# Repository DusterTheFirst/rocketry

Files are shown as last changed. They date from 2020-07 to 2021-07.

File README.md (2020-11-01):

# Thrust Vector Controlled Model Rockets

This repository consists of the rockets that Zachary Kohnen has created. These rockets use active TVC based stabilization.
The models for each rocket can be found in the rockets directory, and the flight firmware for each project can be found in the firmware directory.
Below is a list of the rockets, basic information about them, and hyperlinks to their respective information.

You can access a development log published online at [rocketry.dusterthefirst.com](//rocketry.dusterthefirst.com) file.

# License
    Thrust Vector Controlled Model Rockets
    Copyright (C) 2020  Zachary Kohnen (DusterTheFirst)

    This program is free software: you can redistribute it and/or modify
    it under the terms of the GNU General Public License as published by
    the Free Software Foundation, either version 3 of the License, or
    (at your option) any later version.

    This program is distributed in the hope that it will be useful,
    but WITHOUT ANY WARRANTY; without even the implied warranty of
    MERCHANTABILITY or FITNESS FOR A PARTICULAR PURPOSE.  See the
    GNU General Public License for more details.

    You should have received a copy of the GNU General Public License
    along with this program.  If not, see <https://www.gnu.org/licenses/>.

<sub>All content in this repository was developed and maintained by [@DusterTheFirst (Zachary Kohnen)](https://github.com/dusterthefirst). Software and firmware is licensed under the [`GNU GPL 3.0 license`](./LICENSE.md) and CAD models and other artistic works are licensed under the [`CreativeCommons Attribution-NonCommercial-ShareAlike license`](http://creativecommons.org/licenses/by-nc-sa/4.0/)</sub>

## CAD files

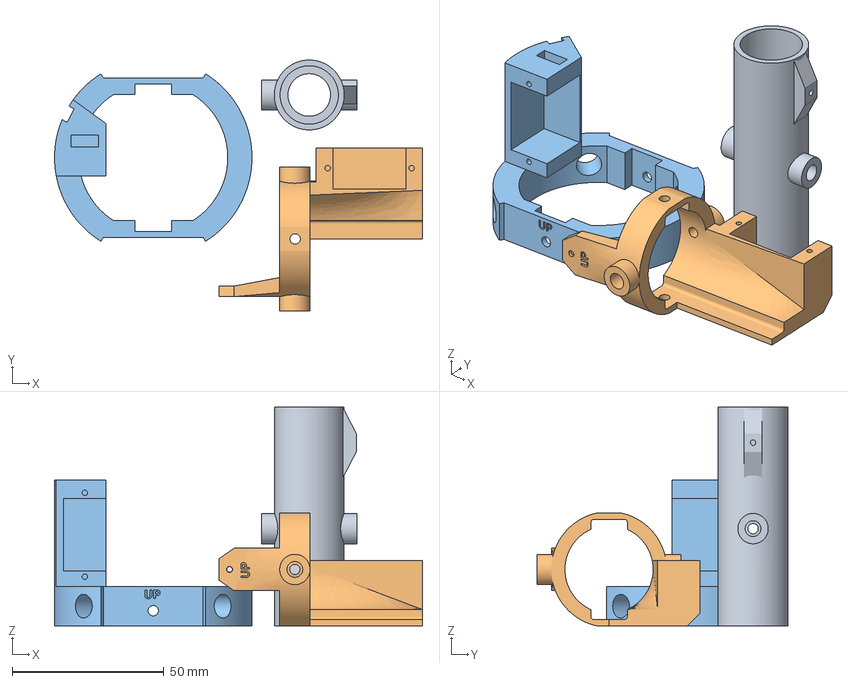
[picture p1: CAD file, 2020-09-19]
rockets/slider/freecad/slice/Full TVC Mount.3mf
121.1 x 82.6 x 72.0 mm
Center Gimbal.stl
Middle Gimbal.stl
Outer Gimbal.stl

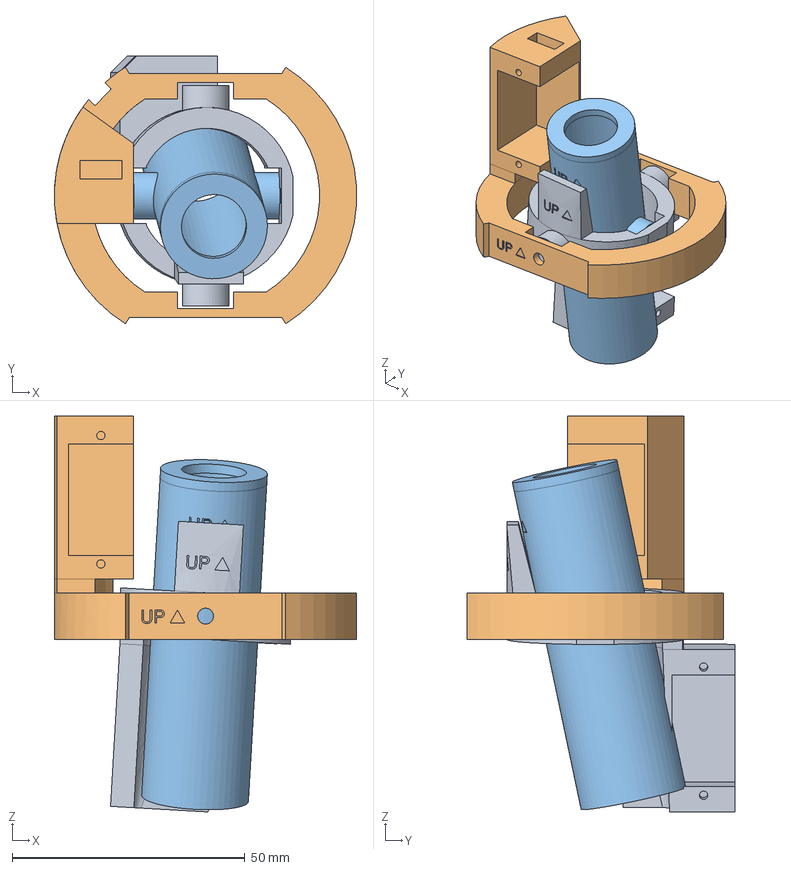
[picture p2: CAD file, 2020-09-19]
rockets/slider/freecad/slider_tvc_assembly.FCStd
64.9 x 57.5 x 85.1 mm
slider_Middle Gimbal_001
slider_Outer Gimbal_001
slider_Center Gimbal_001

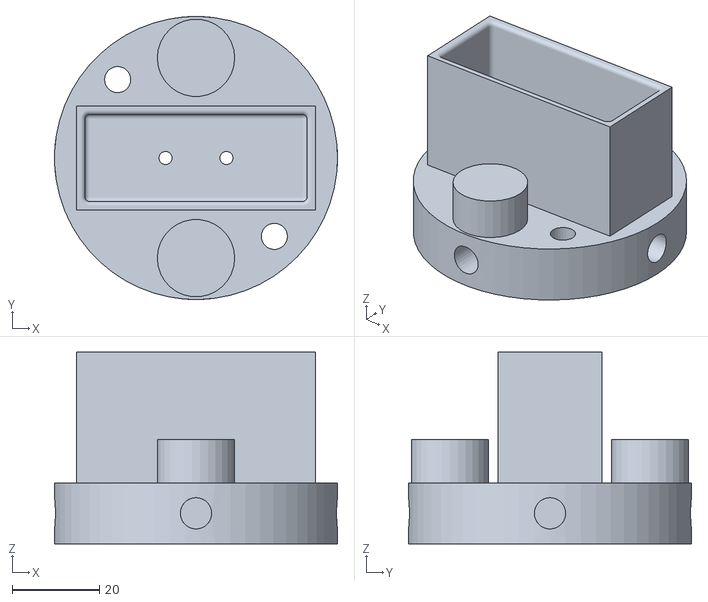
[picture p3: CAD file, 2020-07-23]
rockets/models/slider/renders/Parachute Holder.stl
65.0 x 65.0 x 44.0

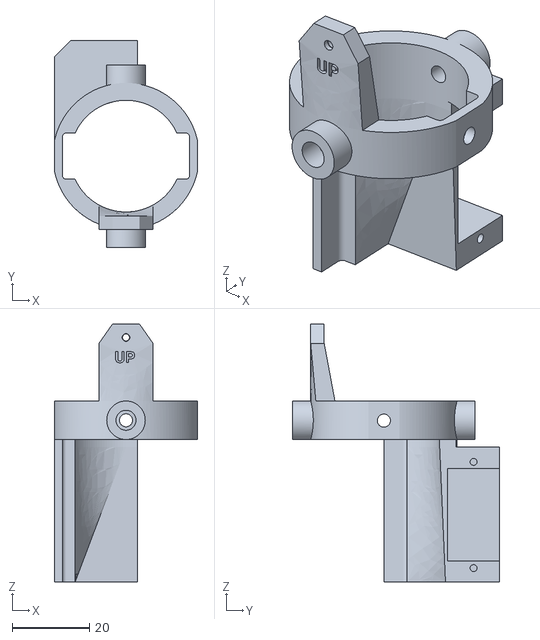
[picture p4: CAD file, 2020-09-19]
rockets/slider/freecad/renders/Middle Gimbal.stl
37.1 x 53.7 x 67.0

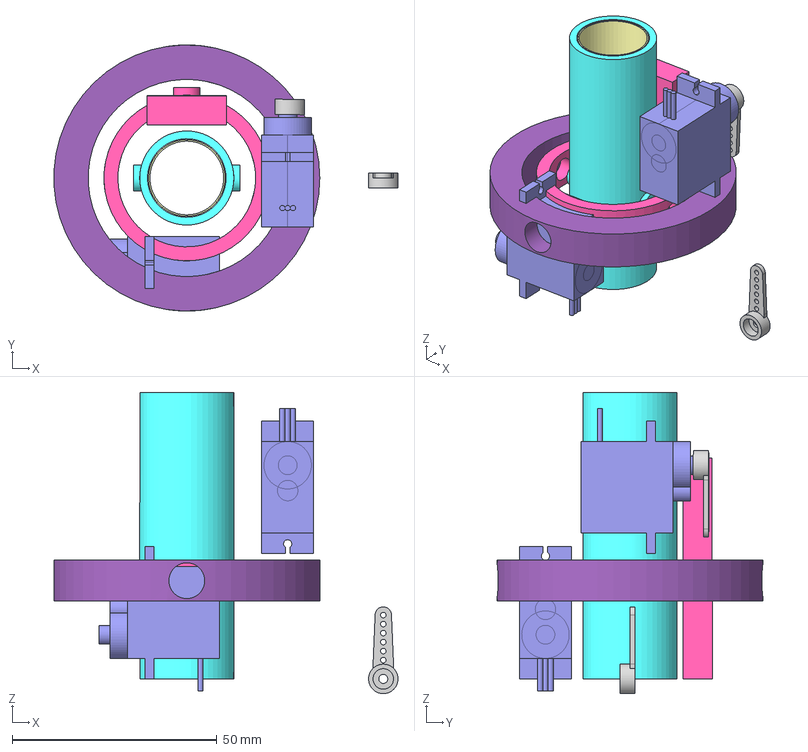
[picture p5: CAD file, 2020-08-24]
rockets/slider/slider.FCStd
84.0 x 65.0 x 73.6 mm
18mm x 2.75" Motor Tube
Center Motor Gimbal
Middle Motor Gimbal
Outer Motor Gimbal
Micro Servo (Tower Pro SG92R) 001 x 2
Micro Servo (Tower Pro SG92R) 002 x 2
Tower Pro Servo Horn 002 x 2
Tower Pro Servo Horn 001 x 2

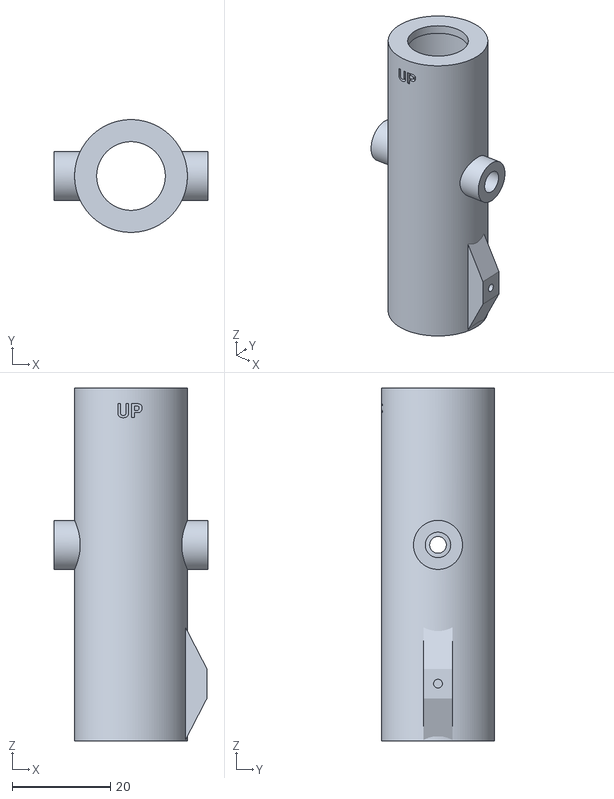
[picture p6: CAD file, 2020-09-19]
rockets/slider/freecad/renders/Center Gimbal.stl
31.4 x 23.0 x 72.0

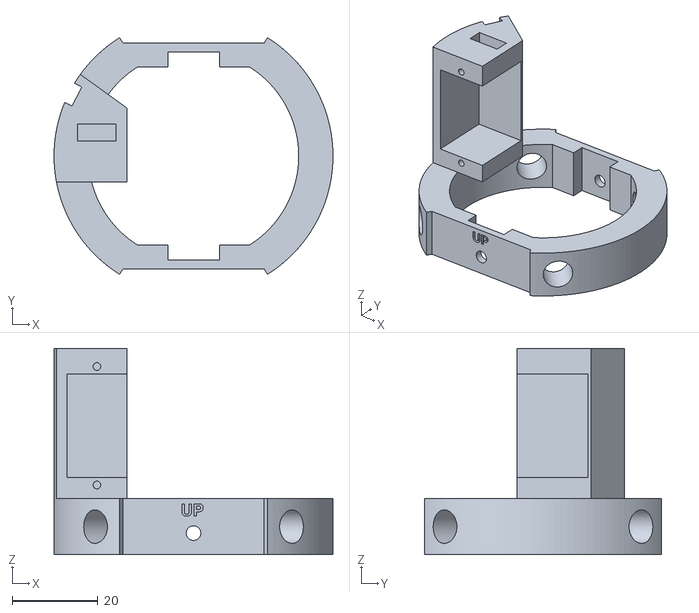
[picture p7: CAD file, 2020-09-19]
rockets/slider/freecad/renders/Outer Gimbal.stl
65.0 x 55.1 x 48.0

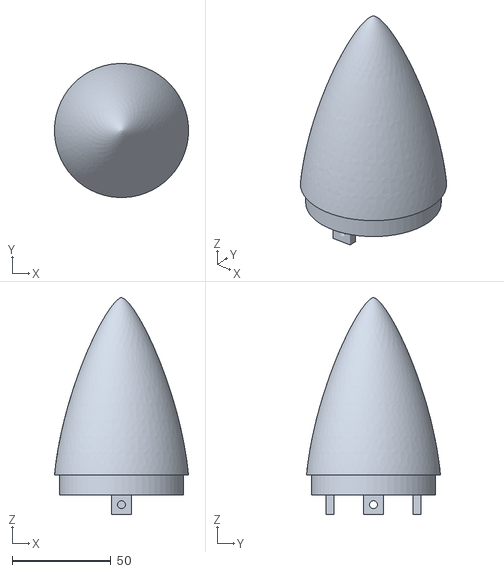
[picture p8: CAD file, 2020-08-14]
rockets/slider/freecad/renders/Nose Cone.stl
68.0 x 67.9 x 110.0

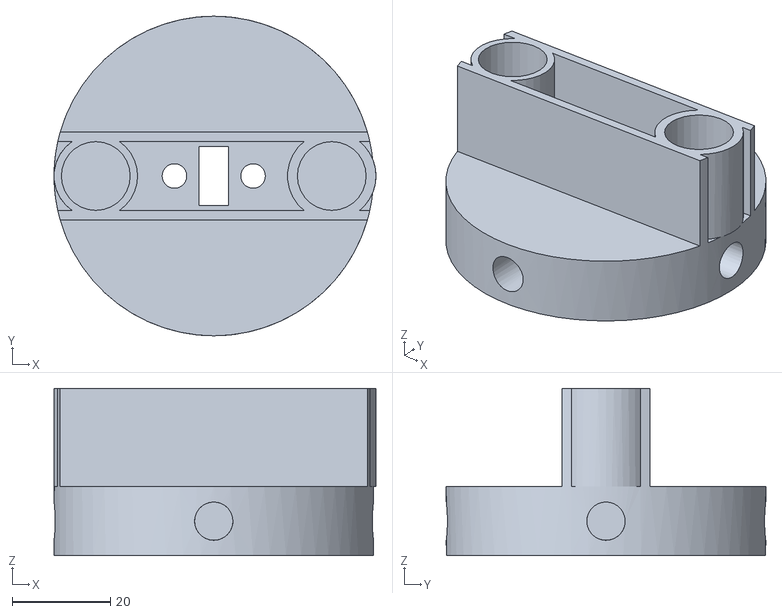
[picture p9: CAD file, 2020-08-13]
rockets/slider/freecad/renders/Parachute Holding.stl
65.5 x 65.0 x 34.0

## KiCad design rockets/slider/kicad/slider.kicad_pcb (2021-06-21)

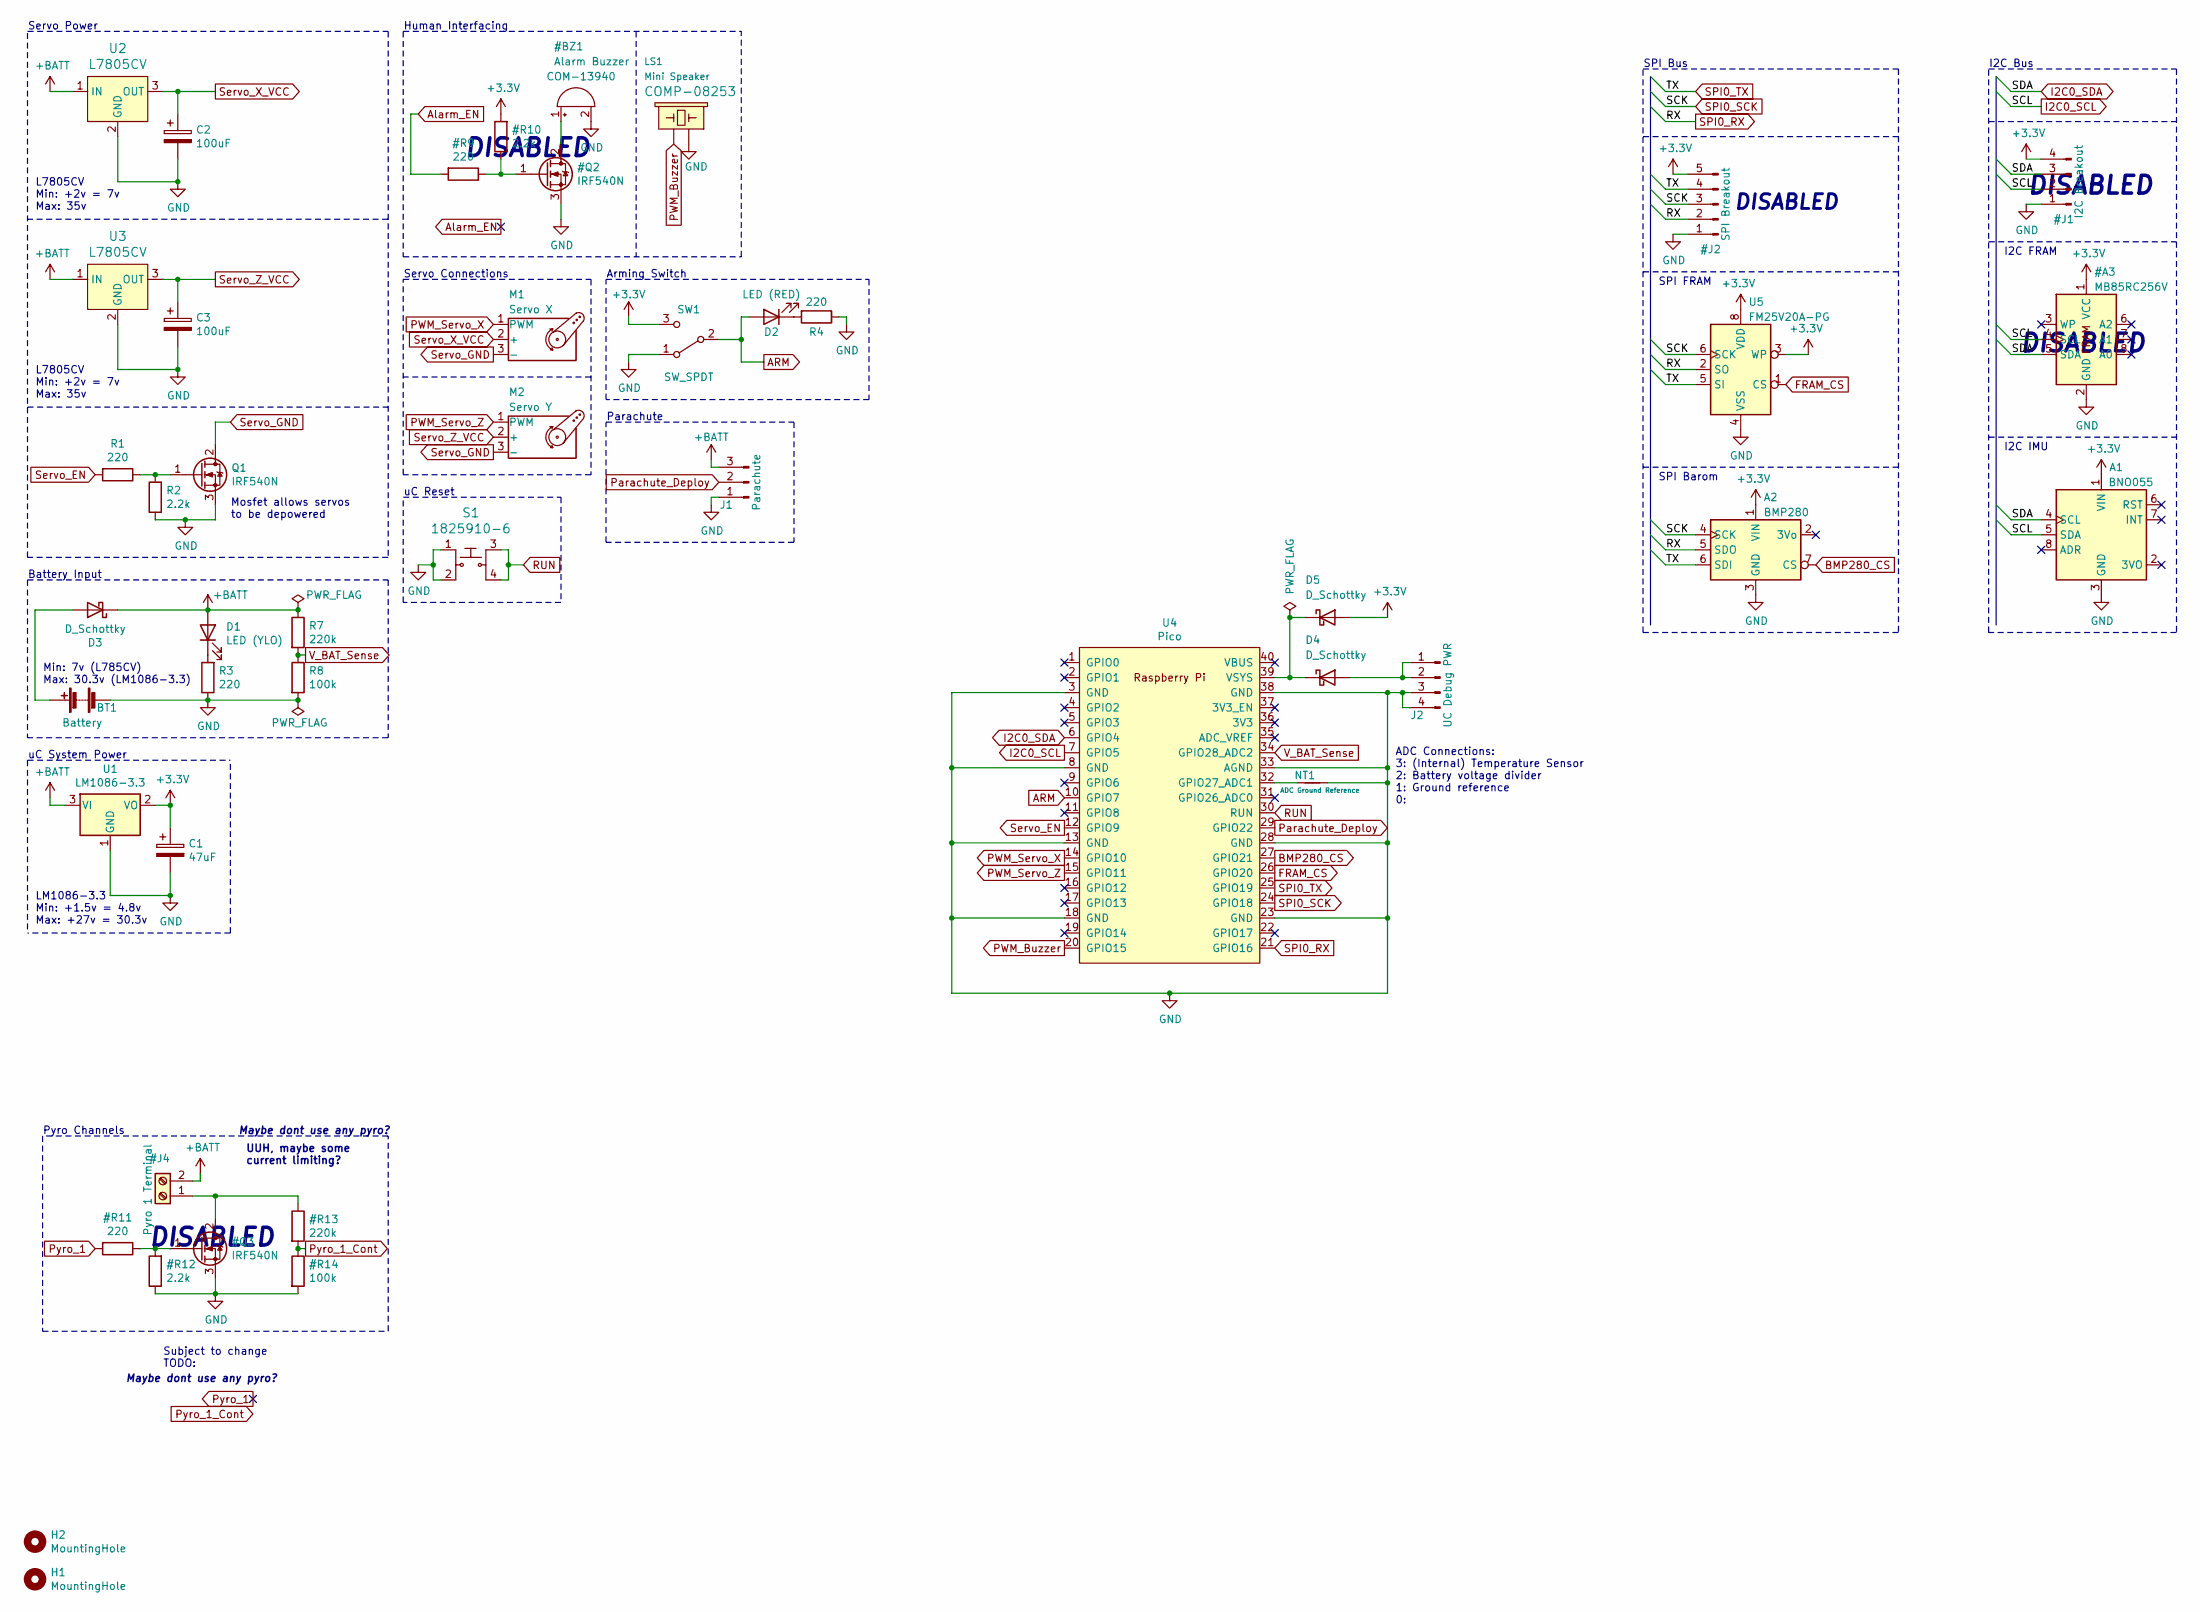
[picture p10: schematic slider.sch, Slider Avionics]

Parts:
A1: BNO055; Adafruit_BNO055
A2: BMP280; Adafruit_BMP280
BT1: Battery; TerminalBlock_Phoenix_PT-1,5-2-3.5-H_1x02_P3.50mm_Horizontal
C1: 47uF; CP_Radial_D5.0mm_P2.50mm
C2, C3: 100uF; CP_Radial_D6.3mm_P2.50mm
D1: LED (YLO); LED_D5.0mm
D2: LED (RED); LED_D5.0mm
D3, D4, D5: D_Schottky; D_DO-35_SOD27_P7.62mm_Horizontal
H1, H2: MountingHole; MountingHole_3mm
J1: Parachute; PinHeader_1x03_P2.54mm_Vertical
J2: UC Debug PWR; PinHeader_1x04_P2.54mm_Vertical
LS1: Mini Speaker; BUZZER-12MM
M1: Servo X; PinHeader_1x03_P2.54mm_Vertical
M2: Servo Y; PinHeader_1x03_P2.54mm_Vertical
NT1: ADC Ground Reference; NetTie-2_SMD_Pad0.5mm
Q1: IRF540N; TO-220-3_Vertical
R1, R3, R4: 220; R_Axial_DIN0207_L6.3mm_D2.5mm_P7.62mm_Horizontal
R2: 2.2k; R_Axial_DIN0207_L6.3mm_D2.5mm_P7.62mm_Horizontal
R7: 220k; R_Axial_DIN0207_L6.3mm_D2.5mm_P7.62mm_Horizontal
R8: 100k; R_Axial_DIN0207_L6.3mm_D2.5mm_P7.62mm_Horizontal
S1: 1825910-6; Switch_Tactile_THT_6x6mm; MPN 1825910-6; Digi-Key_PN 450-1650-ND
SW1: SW_SPDT; Switch_Toggle_ATE1D-2M3-10-Z
U1: LM1086-3.3; TO-220-3_Vertical
U2, U3: L7805CV; TO-220-3_Vertical; MPN L7805CV; Digi-Key_PN 497-1443-5-ND
U4: Pico; RPi_Pico_TH_Perfboard
U5: FM25V20A-PG; FM25V20A

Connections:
ARM: D2.2 (A), SW1.2 (B), U4.10 (GPIO7)
BMP280_CS: A2.7 (CS), U4.27 (GPIO21)
FRAM_CS: U4.26 (GPIO20), U5.1 (CS)
unnamed: BT1.1 (+), D3.2 (A)
unnamed: D1.1 (K), R3.2
unnamed: D2.1 (K), R4.2
unnamed: D4.1 (K), D5.1 (K), U4.39 (VSYS)
unnamed: D4.2 (A), J2.1, J2.2
unnamed: NT1.2, U4.32 (GPIO27_ADC1)
unnamed: Q1.1 (G), R1.1, R2.2
PWM_Buzzer: LS1.+ (1), U4.20 (GPIO15)
PWM_Servo_X: M1.1 (PWM), U4.14 (GPIO10)
PWM_Servo_Z: M2.1 (PWM), U4.15 (GPIO11)
Parachute_Deploy: J1.2, U4.29 (GPIO22)
RUN: S1.3, S1.4, U4.30 (RUN)
Servo_EN: R1.2, U4.12 (GPIO9)
Servo_GND: M1.3 (-), M2.3 (-), Q1.2 (D)
Servo_X_VCC: C2.1, M1.2 (+), U2.3 (OUT)
Servo_Z_VCC: C3.1, M2.2 (+), U3.3 (OUT)
V_BAT_Sense: R7.2, R8.1, U4.34 (GPIO28_ADC2)

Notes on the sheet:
Servo Power
uC System Power
Battery Input
Servo Connections
Human Interfacing
L7805CV Min: +2v = 7v Max: 35v
LM1086-3.3 Min: +1.5v = 4.8v Max: +27v = 30.3v
Min: 7v (L785CV) Max: 30.3v (LM1086-3.3)
uC Reset
Mosfet allows servos to be depowered
UUH, maybe some current limiting?
Pyro Channels
Subject to change TODO:
Arming Switch
Maybe dont use any pyro?
I2C Bus
SPI Bus
I2C FRAM
I2C IMU
SPI FRAM
SPI Barom
DISABLED
Parachute
ADC Connections: 3: (Internal) Temperature Sensor 2: Battery voltage divider 1: Ground reference 0:

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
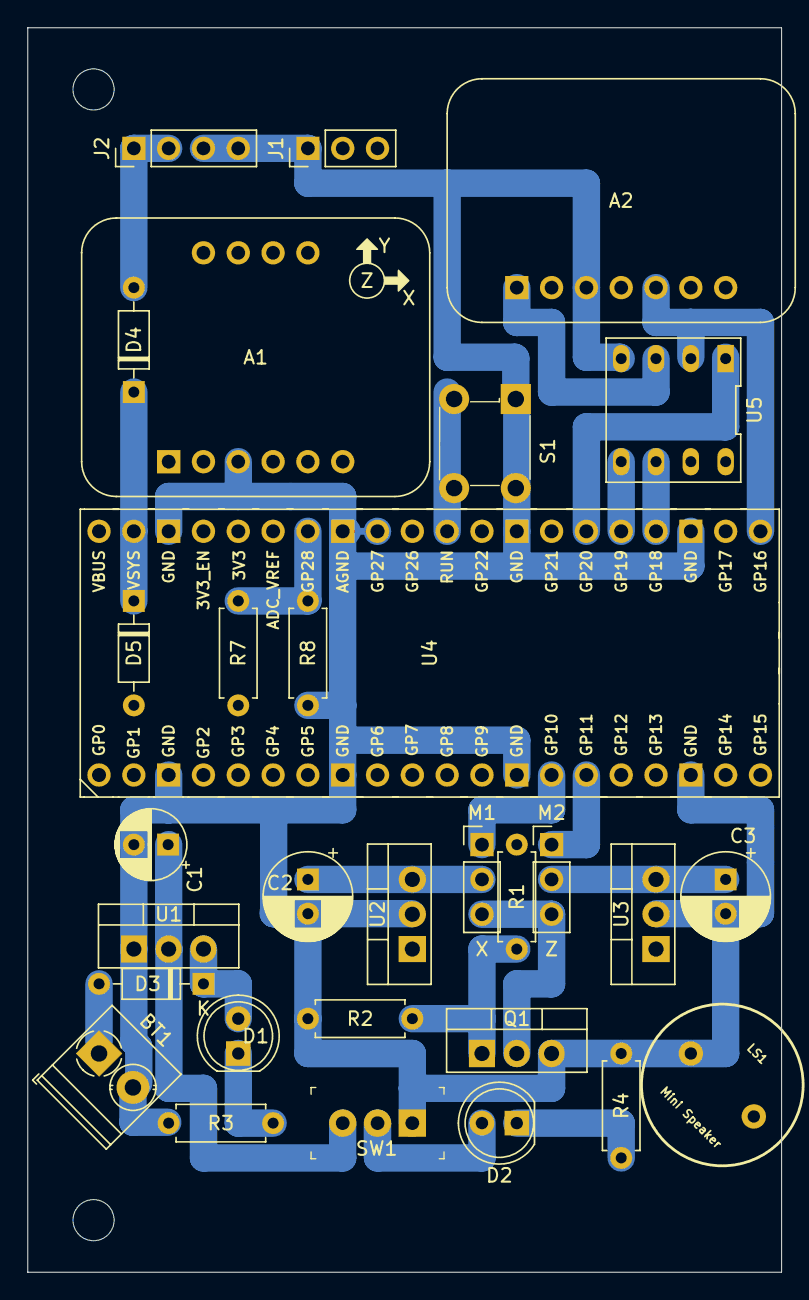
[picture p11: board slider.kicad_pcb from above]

Board: 2 copper layers, 55.0 x 90.8 mm, 33 parts (1 on the bottom side), 28 nets.

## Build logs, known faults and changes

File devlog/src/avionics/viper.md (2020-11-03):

# Viper

> **Status**: In development
> 
> **Created**: August 3, 2020
>
> **First Flown**: Never
>
> **Rockets**: [Slider]

Viper, much like Slider has a lot of rough edges. I, being a software
developer at heart love code that works well and looks good, so I
eventually end up spending way too much time going into detail and
trying to make it perfect while neglecting the hardware. This can be
seen in the [first entry into the devlog][1].

The avionics will control a rocket using TVC given inputs from an IMU.
It will estimate the position of the rocket relative to its position on
the launchpad, attempting to stay pointing towards the sky.

[Slider]: ../rockets/slider.md
[1]: ./viper/2020-11-03-perfection.md

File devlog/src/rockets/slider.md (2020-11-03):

# Slider

> **Status**: In development
> 
> **Created**: July 17, 2020
>
> **First Flown**: Never
>
> **Avionics**: [Viper]

Slider is the first rocket to be made, It is very rough around the edges
but that is expected for a first. The rocket uses TVC based stabilization
during powered flight. The TVC gimbal uses 2 servos to provide around 5
degrees of movement in both directions. The gimbal is able to house any
18mm motor (generally an Estes A-C model rocket motor). The rocket is
only designed for powered flight, it relies on a parachute (or 2) to
slow its decent back to the ground. This parachute system is designed
to use no black powder and to be as reusable and safe as possible.
From testing, [it seems to be very finicky][chute-test] and needs more development
before a good solution is found.

All custom made parts for the rocket are 3d printed out of PLA plastic.
The plastic has been tested and [seems to be able to handle the stress
and heat from the rocket motor][tvc-test].

[Viper]: ../avionics/viper.md
[tvc-test]: ./slider/2020-10-25-tvc.html
[chute-test]: ./slider/2020-08-13-parachute.html

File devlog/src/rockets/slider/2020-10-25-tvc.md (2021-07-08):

# TVC Static Fire I
<sup>October 25, 2020</sup>

## Purpose
This test is designed to test the static force capabilities of the 2 axis TVC gimbal.
Although simple, this test aims to demonstrate that the TVC mount can hold its own under
load as well as maintain its strength under the high temperatures that the motor produces.

## Method
The TVC mount is clamped down to a stand, with the exhaust of the motor facing upwards with
no obstructions directly below or above to allow the exhaust and ejection charge to vent
safely. To protect the grass from the ejection charge, the exhaust guard from a launch pad
is placed below the mount.

<details>
    <summary>The static fire mount setup</summary>
    <a href="https://cdn.dusterthefirst.com/rocketry/rockets/slider/2020/10/25/setup1.jpg">
        
    </a>
</details>

<details>
    <summary>Another angle of the static fire mount setup</summary>
    <a href="https://cdn.dusterthefirst.com/rocketry/rockets/slider/2020/10/25/setup2.jpg">
        
    </a>
</details>

The TVC mount is then filled with a rocket motor tube and a rocket motor with some tape around
the outside in order to increase the friction and ensure the motor does not leave the motor tube.
The motor should be setup with a starter and plug and inserted into the TVC mount's tube.

Once the motor is inserted into the mount, the starter's wires should be attached and area should be cleared.
After the area is prepared and safe, the motor should be fired.

After the motor has finished firing and the ejection charge has been vented, the motor should be removed from
the stand and the TVC mount should be thoroughly inspected for any problems before repeating the process with
another motor.

The process is repeated with both a B4 and C6 estes black powder motor

### 3d Models Used
- [Center Gimbal](https://github.com/DusterTheFirst/rocketry/blob/b0cf1f1de8338ad24c0d549cec9aca23268d9cd0/rockets/slider/renders/Center%20Gimbal.stl)
- [Middle Gimbal](https://github.com/DusterTheFirst/rocketry/blob/b0cf1f1de8338ad24c0d549cec9aca23268d9cd0/rockets/slider/renders/Middle%20Gimbal.stl)
- [Outer Gimbal](https://github.com/DusterTheFirst/rocketry/blob/b0cf1f1de8338ad24c0d549cec9aca23268d9cd0/rockets/slider/renders/Outer%20Gimbal.stl)

The three above models come together to form the TVC gimbal with them nested in descending order,
with the `Center Gimbal` being the inner most layer.

### Footage

#### B motor
<details>
    <summary>Full speed video of a B motor in the test stand <a href="https://cdn.dusterthefirst.com/rocketry/rockets/slider/2020/10/25/static-b-fullspeed.mp4">(link)</a></summary>
    <video height="240" controls>
        <source src="https://cdn.dusterthefirst.com/rocketry/rockets/slider/2020/10/25/static-b-fullspeed.mp4" type="video/mp4">
    </video>
</details>

<details>
    <summary>Slow motion video of a B motor in the test stand <a href="https://cdn.dusterthefirst.com/rocketry/rockets/slider/2020/10/25/static-b-slowmo.mp4">(link)</a></summary>
    <video height="240" controls>
        <source src="https://cdn.dusterthefirst.com/rocketry/rockets/slider/2020/10/25/static-b-slowmo.mp4" type="video/mp4">
    </video>
</details>

#### C motor
<details>
    <summary>Full speed video of a C motor in the test stand <a href="https://cdn.dusterthefirst.com/rocketry/rockets/slider/2020/10/25/static-c-fullspeed.mp4">(link)</a></summary>
    <video height="240" controls>
        <source src="https://cdn.dusterthefirst.com/rocketry/rockets/slider/2020/10/25/static-c-fullspeed.mp4" type="video/mp4">
    </video>
</details>

<details>
    <summary>Slow motion video of a C motor in the test stand <a href="https://cdn.dusterthefirst.com/rocketry/rockets/slider/2020/10/25/static-c-slowmo.mp4">(link)</a></summary>
    <video height="240" controls>
        <source src="https://cdn.dusterthefirst.com/rocketry/rockets/slider/2020/10/25/static-c-slowmo.mp4" type="video/mp4">
    </video>
</details>

## Findings
The PLA plastic was unaffected by the heat of the motor, most probably due to the short amount of time the heat
was applied to the mount and the Kraft Paper motor tube acting as insulation.

The TVC mount held up to the forces of both motors very well, most probably due to the joints being made of
metal screws and metal inserts. There is not data however on how the servos will be able to handle pivoting the
mount under load.

The exhaust from the motor did not affect the bottom (when the rocket is facing upright) of the motor mount however,
the dirty ejection charge left the top of the motor mount covered in soot, but does not seem to have melted any plastic
or caused any deformation to the plastic construction.

## Changes To Implement
None

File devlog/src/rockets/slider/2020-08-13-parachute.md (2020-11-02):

# Parachute Deploy Test I
<sup>August 13, 2020</sup>

## Purpose
To test the nose cone deployment mechanism's practicality and durability before continuing
development of this design

## Method
The nose cone was assembled with nylon fishing line with nichrome wire wrapped around each tie down line which was then fed
through the holes in the parachute holder and around a push-rod perpendicular to the hole to hold them in place.
The nichrome wire was then supplied current, heating it up and eventually melting the nylon wires.

### 3d Models Used
- [Nose Cone](https://github.com/DusterTheFirst/rocketry/blob/a1a50608c714fe1a907a077f69319fac23ef29f5/rockets/slider/renders/Nose%20Cone.stl)
- [Parachute Holder](https://github.com/DusterTheFirst/rocketry/blob/a1a50608c714fe1a907a077f69319fac23ef29f5/rockets/slider/renders/Parachute%20Holder.stl)

## Findings
The nichrome wire is very reliable in heating up, but not enough that we can guarantee
two nichrome wires to cut through their hold down strings at the same time. In the test,
only one of the wires was cut before the nosecone flew off. When the nose cone was released,
it remained attached to the hold down assembly due to one of the hold down lines remaining uncut.
This lead us to understand that in order to use nichrome wire as a release mechanism,
we must design the release in such a way that it will only use one hold down point.

## Changes To Implement
- Redesign Nose Cone [(done)](https://github.com/DusterTheFirst/rocketry/blob/00949badd6df8fbdd533ba6b04284b056b241a8f/rockets/slider/renders/Nose%20Cone.stl)
    - One, central, tie down point
    - Attachment point(s) for parachute(s)
- Redesign parachute holding mechanism [(done)](https://github.com/DusterTheFirst/rocketry/blob/00949badd6df8fbdd533ba6b04284b056b241a8f/rockets/slider/renders/Parachute%20Holding.stl)
    - One central tie down point
    - Container(s) for parachute(s)
    - Gap around where nichrome wire will be placed as to not melt any PLA plastic

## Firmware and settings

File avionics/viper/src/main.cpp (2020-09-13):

#include "interop/cpp.h"
#include "oxide.h"
#include <Adafruit_BMP280.h>
#include <Adafruit_BNO055.h>
#include <Adafruit_Sensor.h>
#include <Arduino.h>
#include <InternalTemperature.h>
#include <Plotter.h>
#include <Wire.h>

Adafruit_BNO055 bno(55, 0x29);
Adafruit_BMP280 bmp;

Plotter p;

Avionics avionics = create_avionics();
SensorData *data = &avionics.sensor_data;

void setup() {
    p.Begin(); // start plotter

    // BNO-055
    p.AddTimeGraph("Absolute Orientation (deg)", 300,
                   "X", data->bno055.orientation.euler.x,
                   "Y", data->bno055.orientation.euler.y,
                   "Z", data->bno055.orientation.euler.z);
    // p.AddTimeGraph("Absolute Orientation (quaterion)", 300,
    //                "W", data->bno055.orientation.quaterion.w(),
    //                "X", data->bno055.orientation.quaterion.x(),
    //                "Y", data->bno055.orientation.quaterion.y(),
    //                "Z", data->bno055.orientation.quaterion.z());
    p.AddTimeGraph("Angular Velocity (rad/s)", 300,
                   "X", data->bno055.angular_velocity.x,
                   "Y", data->bno055.angular_velocity.y,
                   "Z", data->bno055.angular_velocity.z);
    p.AddTimeGraph("Acceleration (m/s^2)", 300,
                   "X", data->bno055.acceleration.both.x,
                   "Y", data->bno055.acceleration.both.y,
                   "Z", data->bno055.acceleration.both.z);
    p.AddTimeGraph("Linear Acceleration (m/s^2)", 300,
                   "X", data->bno055.acceleration.linear.x,
                   "Y", data->bno055.acceleration.linear.y,
                   "Z", data->bno055.acceleration.linear.z);
    p.AddTimeGraph("Gravity (m/s^2)", 300,
                   "X", data->bno055.acceleration.gravity.x,
                   "Y", data->bno055.acceleration.gravity.y,
                   "Z", data->bno055.acceleration.gravity.z);
    p.AddTimeGraph("Magnetic Field (uT)", 300,
                   "X", data->bno055.magnetic_field.x,
                   "Y", data->bno055.magnetic_field.y,
                   "Z", data->bno055.magnetic_field.z);
    p.AddTimeGraph("Preassure and Altitude", 300,
                   "Pressure (Pa)", data->bmp280.pressure,
                   "Approx. Altitude (m)", data->bmp280.altitude);
    p.AddTimeGraph("Temperature (*C)", 300,
                   "BNO-055", data->bno055.temperature,
                   "BMP-280", data->bmp280.temperature,
                   "Teensy", data->teensy.temperature);

    /* Initialise the sensors */
    if (!bno.begin()) {
        Serial.print("Could not connect to BNO055");

        error_chime(Peripheral::BNO055);
    }

    bno.setExtCrystalUse(true);

    if (!bmp.begin()) {
        Serial.println("Could not connect to BMP280");

        error_chime(Peripheral::BMP280);
    }

    init_avionics(&avionics);
    startup_chime();
}

void loop_1Hz() {
    data->bno055.temperature = bno.getTemp();
    data->bmp280.temperature = bmp.readTemperature();
    data->teensy.temperature = InternalTemperature.readTemperatureC();
}

void loop_10Hz() {
}

void loop_20Hz() {
    data->bno055.magnetic_field = to_rust_vec(bno.getVector(Adafruit_BNO055::VECTOR_MAGNETOMETER));
}

void loop_100Hz() {
    data->bno055.acceleration.both = to_rust_vec(bno.getVector(Adafruit_BNO055::VECTOR_ACCELEROMETER));
    data->bno055.acceleration.linear = to_rust_vec(bno.getVector(Adafruit_BNO055::VECTOR_LINEARACCEL));
    data->bno055.acceleration.gravity = to_rust_vec(bno.getVector(Adafruit_BNO055::VECTOR_GRAVITY));
    data->bno055.angular_velocity = to_rust_vec(bno.getVector(Adafruit_BNO055::VECTOR_GYROSCOPE));
    data->bno055.orientation.euler = to_rust_vec(bno.getVector(Adafruit_BNO055::VECTOR_EULER));
    // data->bno055.orientation.quaterion = bno.getQuat();

    data->bmp280.pressure = bmp.readPressure();
    data->bmp280.altitude = bmp.readAltitude(1017.6097943333434);

    p.Plot();
}

uint32_t last_1hz_clock = 0;
uint32_t last_10hz_clock = 0;
uint32_t last_20hz_clock = 0;
uint32_t last_100hz_clock = 0;

void loop() {
    uint32_t current_millis = millis();

    if (current_millis - last_1hz_clock > 1000) {
        loop_1Hz();
        last_1hz_clock = current_millis;
    }

    if (current_millis - last_10hz_clock > 100) {
        loop_10Hz();
        last_10hz_clock = current_millis;
    }

    if (current_millis - last_20hz_clock > 50) {
        loop_20Hz();
        last_20hz_clock = current_millis;
    }

    if (current_millis - last_100hz_clock > 10) {
        loop_100Hz();
        last_100hz_clock = current_millis;
    }

    tick_avionics(&avionics);
}

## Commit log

2020-07-23 Initial File Structure
    [Nose Cone.stl, Parachute Holder.stl, rocket.FCStd]
2020-07-23 rename stl folder to renders
    [Nose Cone.stl, Parachute Holder.stl]
2020-07-23 Rename cad models to rignt name
    [rocket.FCStd, slider.FCStd]
2020-07-25 Add parachute hoop to nose cone
    [Nose Cone.stl, slider.FCStd]
2020-07-29 Better, lighter nose cone
    [Nose Cone.stl, slider.FCStd]
2020-07-31 Stronger springs
    [Nose Cone.stl, slider.FCStd]
2020-07-31 Fix export
    [slider.FCStd]
2020-08-03 REorganise file structure
    [Nose Cone.stl, Parachute Holder.stl, slider.FCStd]
2020-08-08 new nose cone mount
    [slider.FCStd]
2020-08-13 New nose cone and parachute holder
    Two hold down strings will not work with the nichrome wire design due to them releasing at different times
    [Nose Cone.stl, Parachute Holder.stl, Parachute Holding.stl]
2020-08-13 Addition of devlog and rename of firmware directory to avionics
    [slider.FCStd]
2020-08-14 More hollow nosecone
    [Nose Cone.stl, slider.FCStd]
2020-08-24 Beginnings of TVC mount
    [slider.FCStd]
2020-08-24 Better design of TVC mount
2020-08-28 More TVC Gimbal Mount
    [Center Gimbal.stl, Middle Gimbal.stl, Outer Gimbal.stl]
2020-08-29 Better Middle TVC Mount
2020-08-31 Added drill holes to the middle gimbal
    [Middle Gimbal.stl]
2020-08-31 Added more support under servo carrage and made the servo wires cutout better for 3d printing
2020-08-31 Exported new middle gimbal
    [Middle Gimbal.stl]
2020-09-03 Thicker band around threaded inserts on gimbal
2020-09-04 Both servos aligned, just need to setup the connection mechanism ;)
2020-09-10 move to teensyuino and submodule
2020-09-13 Documentation and servo pushrods
2020-09-13 move to stable rust and some move towards reading in sensors
2020-09-13 revert back to the c hybrid approach since the other one ran super slow for some reason
    [main.cpp]
2020-09-18 Probbably v1 of gimbal done
    [Center Gimbal.stl, Middle Gimbal.stl, Outer Gimbal.stl]
2020-09-19 Finishing touches on TVC mount v1
    [Center Gimbal.stl, Full TVC Mount.3mf, Middle Gimbal.stl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]
2021-03-27 new work on pcb
    [Center Gimbal.stl, Full TVC Mount.3mf, Middle Gimbal.stl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]
2021-03-28 More shematic
    [slider.sch]
2021-03-28 Change schematic layout
    [slider.sch]
2021-04-12 assigned footprints
    [slider.sch]
2021-04-18 loads of pcb shiz
    [slider.kicad_pcb, slider.sch]
2021-05-29 Lots of work on busses and sensors
    [slider.sch]
2021-05-31 Lots of 3d models for kicad and rethinking the pcb design
    [slider.kicad_pcb, slider.sch]
2021-06-19 Move custom library to https://github.com/DusterTheFirst/kicad-library
2021-06-19 Near v1 of board layout
    [slider.kicad_pcb, slider.sch]
2021-06-21 Routing and an additional pin header
    [slider.kicad_pcb, slider.sch]
